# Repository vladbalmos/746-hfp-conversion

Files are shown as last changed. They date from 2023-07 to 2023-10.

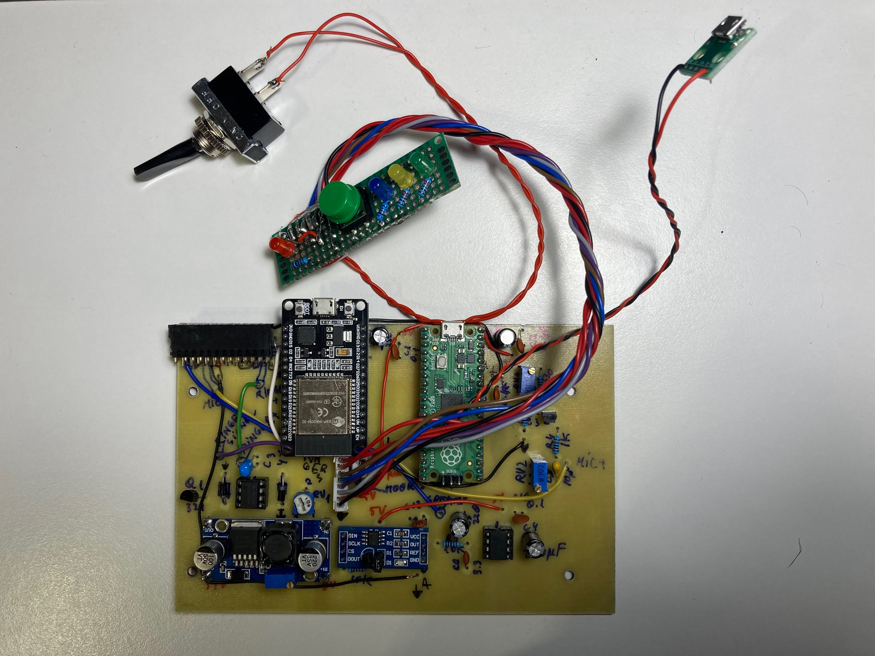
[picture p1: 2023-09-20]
img/main-board-pcb-front.jpg

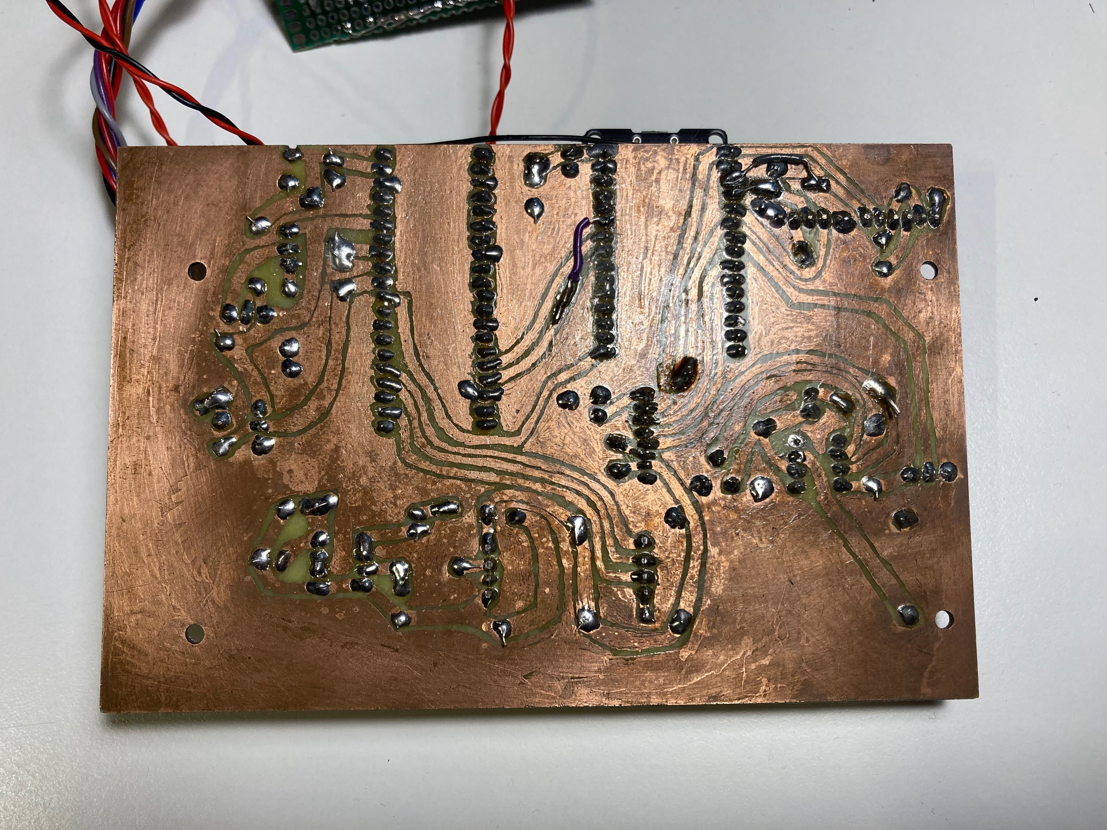
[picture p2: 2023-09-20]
img/main-board-pcb-back.jpg

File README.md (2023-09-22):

## British GPO 746 bluetooth conversion (HFP)

Firmware and hardware related resources for adding hands-free bluetooth support to a 746 british phone.

## Hardware requirements

* esp32 devboard (v1)
* Raspberry PI Pico
* external DAC (TLC5615)
* GPO 746 telephone

## Software dependencies

* esp-idf (v5.1)
* pico-sdk ( >= v1.5.0)
* opencd (optional)
* picoprobe (optiona)

## Audio input/output

In a nutshell, the ESP32 is configured with `SCO data path = HCI`, this enables the improved mSBC codec on some AGs; the audio in/out is received/sent from/to a Raspberry Pi Pico I2C slave, acting as a recording/playback device.  
The microphone is sampled using the Pico's 12bit ADC, while the earpiece speaker is driven by a buffered 10bit external DAC which interfaces with the Pico using SPI.

This is more complicated than it should mostly due to my lack of experience with the ESP32 and lack of a propper external ADC.  
My initial plan was to use the ESP32's ADC & DAC simultaneous, but the I've run into the following problems:
1. the ADC & DAC cannot be used at the same time in DMA Mode, since they both share the same DMA fifo of the I2S0 peripheral: [ADC continuous mode Hardware Limitations](https://docs.espressif.com/projects/esp-idf/en/v5.1/esp32/api-reference/peripherals/adc_continuous.html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) - I couldn't find any proper way of making it work
2. even if both ADC & DAC could work in continuous DMA mode, the ADC configuration doesn't allow sampling frequencies below 20khz (for mSBC & CVSD codecs a lower sampling rate is required: 16khz, 8khz respectively)
3. the ESP32 doesn't have an analog ground which makes both the ADC & DAC really noisy

In a previous iteration of the project, both the Pico and the external DAC were connected to the ESP32 via SPI, but it struggled to keep a constant rate of sending/receiving PCM samples during an active call because each PCM sample required its own SPI transaction (both the Pico and the TLC5615 support only 2 byte transactions) - this caused horrible audio on both ends.

## Audio transmission
The Pico is configured as a slave I2C device receiving and transmitting audio data at the master's request (ESP32). Data is transmitted via a basic protocol built on top of I2C which consists of 5 commands. Each command is encoded as a 16 bit uint. The first 8 MSB encode the command code and the last 8 LSB encode any arguments the command might have.  
Commands:  

* AUDIO_ENABLE  
    Enable ADC/DAC. The sample rate is given as a parameter
* AUDIO_DISABLE  
    Disable ADC/DAC
* AUDIO_POLL
    Poll the slave for new audio data sampled by the ADC. If slave returns `true`, the AUDIO_RECEIVE command is sent to the slave to receive the PCM samples
* AUDIO_TRANSMIT
    Sent by the master to transmit PCM samples for playback
* AUDIO_RECEIVE
    Sent by the master to receive new PCM samples from the ADC

Basic data flow between ESP32 and PICO:

    1. (master) send AUDIO_ENABLE command
       (slave) initialize ADC & DAC using the sample rate encoded in the command
       (slave) respond with OK
    2. (master) transmit any buffered PCM samples for playback (AUDIO_TRANSMIT)
       (slave) receive PCM samples and transmit to DAC via DMA
    3. (master) poll slave for new samples (AUDIO_POLL). If reply is OK, send AUDIO_RECEIVE command to receive new samples

## Functions

Almost all the existing features of the GPO 746 are preserved once paired via Bluetooth HFP:

* Ringing works when an incoming call is detected. The ringer is driven by a AC coupled PWM 20hz signal amplified to 34V using a DC-DC voltage booster module.
* Earpiece / microphone
* Dialing via the rotary dialer works as expected

Visual indicator LEDs available for:

* power
* ringing
* bluetooth connection state
* handset on/off hook

A schematic on how to physically connect the phone to the board will be added soon.

## Building

The boards need to be separately flashed using the code in `src`.

### esp32

    cd src/esp32
    source /path/to/esp-idf/export.sh
    idf.py build flash

### pico
If using picoprobe and opencd:

    # open pico-install.sh.template and change the path to opencd binary
    # rename pico-install.sh.template to pico-install.sh
    # make pico-install.sh executable
    # copy pico-install.sh to a folder which is in your $PATH (I usually place this little scripts in ~/bin)
    cd src/pico
    make install

If not using picoprobe & opencd just build and flash using the manual steps provided in the getting started pico-sdk guide

## PCBs
The device is split into two PCBs, a main board and a control board. The main board houses all the relevant components for bluetooth and audio while the control board contains the indicator LEDs and a microswitch for toggling bluetooth pairing. The schematics and PCB designs were done using KiCad, all documents are inside the `hw` folder. I designed the main board to be single sided, but the pcb design file contains traces and vias for a two sided board only to pass DRC validation and given that I manually trace and etch my PCBs I cannot guarantee that the final designs are good enough for sending to a PCB manufacturer. Inspect the designs and tweak accordingly before ordering a set of boards. You can find some pictures of the boards in the `img` folder. 

A 3d printed case model will be available in the future inside `hw/3d-prints`.

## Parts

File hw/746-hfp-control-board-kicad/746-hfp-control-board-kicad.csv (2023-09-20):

Source: | /home/vlad/Development/hw/esp32/projects/746-bt-conversion/hw/746-hfp-control-board-kicad/746-hfp-control-board-kicad.kicad_sch
Date: | Wed 20 Sep 2023 21:17:07 EEST
Tool: | Eeschema 7.0.7-7.0.7~ubuntu22.04.1
Generator: | /usr/share/kicad/plugins/bom_csv_grouped_by_value.py
Component Count: | 11
Collated Components:
Item | Qty | Reference(s) | Value | LibPart | Footprint | Datasheet | DNP
1 | 4 | D1, D2, D3, D4 | LED | Device:LED | LED_THT:LED_D5.0mm | ~
2 | 1 | J1 | Control_board_Connector | Connector:Conn_01x08_Socket | Connector_PinSocket_2.54mm:PinSocket_1x08_P2.54mm_Vertical | ~
3 | 2 | R1, R3 | 220 | Device:R | Resistor_THT:R_Axial_DIN0207_L6.3mm_D2.5mm_P10.16mm_Horizontal | ~
4 | 1 | R2 | 2k | Device:R | Resistor_THT:R_Axial_DIN0207_L6.3mm_D2.5mm_P10.16mm_Horizontal | ~
5 | 1 | R4 | 1k | Device:R | Resistor_THT:R_Axial_DIN0207_L6.3mm_D2.5mm_P10.16mm_Horizontal | ~
6 | 1 | SW1 | SW_Push | Switch:SW_Push | Button_Switch_THT:SW_PUSH_6mm_H5mm | ~
7 | 1 | SW2 | SW_SPST | Switch:SW_SPST | Connector_PinHeader_2.54mm:PinHeader_1x02_P2.54mm_Vertical | ~

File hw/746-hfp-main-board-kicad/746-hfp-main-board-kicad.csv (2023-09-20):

Source: | /home/vlad/Development/hw/esp32/projects/746-bt-conversion/hw/746-hfp-main-board-kicad/746-hfp-main-board-kicad.kicad_sch
Date: | Wed 20 Sep 2023 21:15:39 EEST
Tool: | Eeschema 7.0.7-7.0.7~ubuntu22.04.1
Generator: | /usr/share/kicad/plugins/bom_csv_grouped_by_value.py
Component Count: | 44
Collated Components:
Item | Qty | Reference(s) | Value | LibPart | Footprint | Datasheet | DNP | Sim.Device | Sim.Params | Sim.Pins | Sim.Type
1 | 3 | C1, C2, C13 | 0.1uf | Device:C | Capacitor_THT:C_Disc_D4.7mm_W2.5mm_P5.00mm | ~
2 | 1 | C3 | 47uF | Device:C | Capacitor_THT:C_Radial_D6.3mm_H11.0mm_P2.50mm | ~
3 | 4 | C4, C5, C11, C12 | 220uF | Device:C_Polarized | Capacitor_THT:C_Radial_D6.3mm_H11.0mm_P2.50mm | ~
4 | 1 | C6 | 3.3nF | Device:C | Capacitor_THT:C_Disc_D4.7mm_W2.5mm_P5.00mm | ~
5 | 1 | C8 | 10uF | Device:C | Capacitor_THT:C_Disc_D4.7mm_W2.5mm_P5.00mm | ~
6 | 1 | C9 | 0.1uF | Device:C | Capacitor_THT:C_Disc_D4.7mm_W2.5mm_P5.00mm | ~
7 | 1 | C10 | 0.1uF | Device:C | Capacitor_THT:C_Radial_D6.3mm_H11.0mm_P2.50mm | ~
8 | 2 | D1, D2 | 1N5819 | Device:D_Schottky | Diode_THT:D_DO-41_SOD81_P10.16mm_Horizontal | ~
9 | 1 | J1 | 5V | :Conn_01x01_Socket_1 | Connector_PinSocket_2.54mm:PinSocket_1x01_P2.54mm_Vertical | ~
10 | 1 | J2 | GND | :Conn_01x01_Socket_2 | Connector_PinSocket_2.54mm:PinSocket_1x01_P2.54mm_Vertical | ~
11 | 1 | J3 | 34V | :Conn_01x01_Socket_3 | Connector_PinSocket_2.54mm:PinSocket_1x01_P2.54mm_Vertical | ~
12 | 1 | J4 | GND | Connector:Conn_01x01_Socket | Connector_PinSocket_2.54mm:PinSocket_1x01_P2.54mm_Vertical | ~
13 | 4 | J5, J9, J10, J11 | Conn_01x01_Socket | Connector:Conn_01x01_Socket | Connector_PinSocket_2.54mm:PinSocket_1x01_P2.54mm_Vertical | ~
14 | 1 | J6 | Conn_01x01_Socket | :Conn_01x01_Socket_3 | Connector_PinSocket_2.54mm:PinSocket_1x01_P2.54mm_Vertical | ~
15 | 1 | J7 | Conn_01x01_Socket | :Conn_01x01_Socket_2 | Connector_PinSocket_2.54mm:PinSocket_1x01_P2.54mm_Vertical | ~
16 | 1 | J8 | Conn_01x01_Socket | :Conn_01x01_Socket_1 | Connector_PinSocket_2.54mm:PinSocket_1x01_P2.54mm_Vertical | ~
17 | 1 | J12 | Phone_Connector | Connector:Conn_01x12_Socket | Connector_PinSocket_2.54mm:PinSocket_1x12_P2.54mm_Vertical | ~
18 | 1 | J13 | ESP32_Left_Pins | Connector:Conn_01x15_Pin | Connector_PinSocket_2.54mm:PinSocket_1x15_P2.54mm_Vertical | ~
19 | 1 | J14 | ESP32_Right_Pins | :Conn_01x15_Pin_1 | Connector_PinSocket_2.54mm:PinSocket_1x15_P2.54mm_Vertical | ~
20 | 1 | J15 | Power_Connector | Connector_Generic:Conn_01x02 | Connector_JST:JST_XH_B2B-XH-A_1x02_P2.50mm_Vertical | ~
21 | 1 | J17 | Control_board_connector | Connector:Conn_01x08_Pin | Connector_JST:JST_PH_B8B-PH-K_1x08_P2.00mm_Vertical | ~
22 | 1 | J18 | Conn_01x01_Socket | :Conn_01x01_Socket_4 | Connector_PinSocket_2.54mm:PinSocket_1x01_P2.54mm_Vertical | ~
23 | 1 | Q1 | 2N7000 | Simulation_SPICE:NMOS | Package_TO_SOT_THT:TO-92 | https://ngspice.sourceforge.io/docs/ngspice-manual.pdf |  | NMOS |  | 1=D 2=G 3=S | VDMOS
24 | 2 | R3, R7 | 10k | Device:R | Resistor_THT:R_Axial_DIN0207_L6.3mm_D2.5mm_P10.16mm_Horizontal | ~
25 | 1 | R4 | 1k | Device:R | Resistor_THT:R_Axial_DIN0207_L6.3mm_D2.5mm_P10.16mm_Horizontal | ~
26 | 1 | R5 | 330 | Device:R | Resistor_THT:R_Axial_DIN0207_L6.3mm_D2.5mm_P10.16mm_Horizontal | ~
27 | 1 | R6 | 100k | Device:R | Resistor_THT:R_Axial_DIN0207_L6.3mm_D2.5mm_P10.16mm_Horizontal | ~
28 | 1 | RV1 | 100k | Device:R_Potentiometer_Trim | Potentiometer_THT:Potentiometer_Runtron_RM-065_Vertical | ~
29 | 1 | RV2 | 10k | Device:R_Potentiometer_Trim | Potentiometer_THT:Potentiometer_Bourns_3296W_Vertical | ~
30 | 1 | RV3 | 100k | Device:R_Potentiometer_Trim | Potentiometer_THT:Potentiometer_Bourns_3296W_Vertical | ~
31 | 1 | U2 | Pico | MCU_RaspberryPi_and_Boards:Pico | MCU_RaspberryPi_and_Boards:RPi_Pico_SMD_TH
32 | 1 | U3 | TL431P | Reference_Voltage:TL431P | Package_TO_SOT_THT:TO-92_Inline_Wide | http://www.ti.com/lit/ds/symlink/tl431.pdf
33 | 1 | U4 | LM358 | Amplifier_Operational:LM358 | Package_DIP:DIP-8_W7.62mm_Socket_LongPads | http://www.ti.com/lit/ds/symlink/lm2904-n.pdf
34 | 1 | U5 | UA741 | Simulation_SPICE:OPAMP | Package_DIP:DIP-8_W7.62mm_Socket_LongPads | ~ |  | SPICE | type="X" model="OPAMP" lib="" | 1=1 2=2 3=3 4=4 5=5

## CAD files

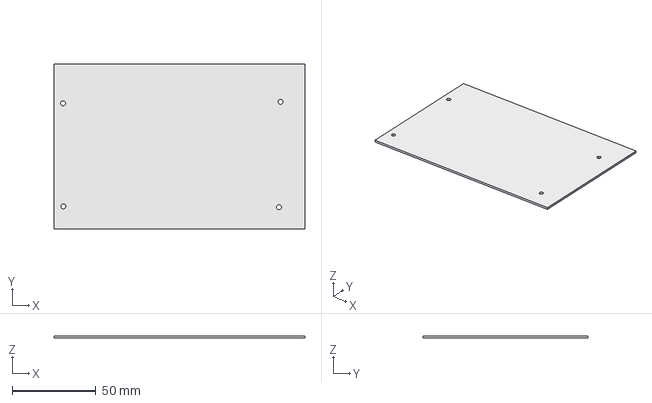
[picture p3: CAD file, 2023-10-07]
hw/3d-prints/enclosure/enclosure.FCStd
150.0 x 98.5 x 1.45 mm

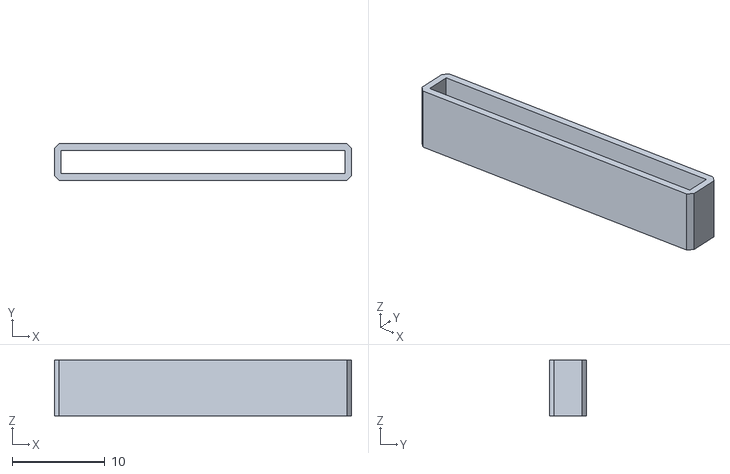
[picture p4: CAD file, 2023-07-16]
hw/3d-prints/header-pin-connector-housing/header-pin-connector-housing-Body.stl
32.0 x 4.00 x 6.00

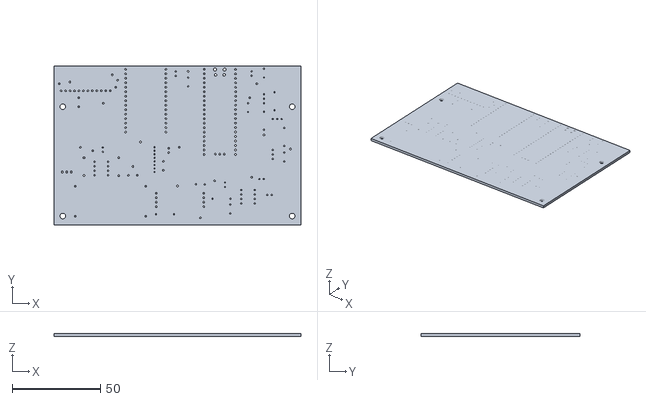
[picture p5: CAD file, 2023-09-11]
hw/3d-prints/pcb-holes-template/pcb-holes.stl
140.0 x 90.0 x 1.58

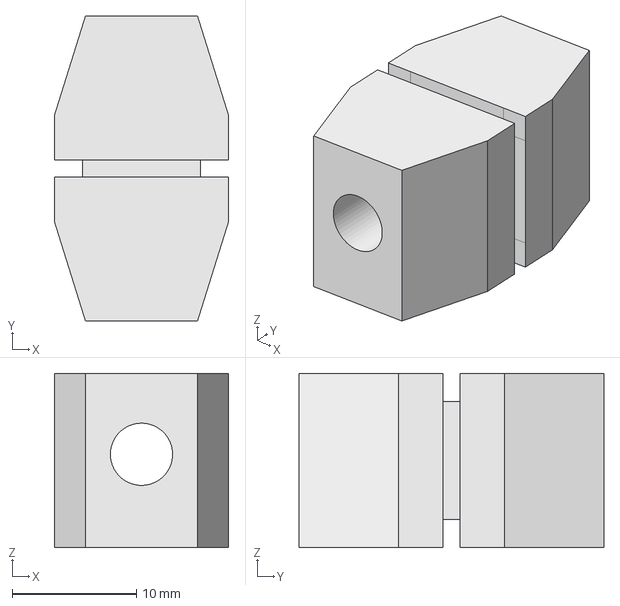
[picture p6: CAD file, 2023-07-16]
hw/3d-prints/strain-relief/connector-strain-relief.FCStd
14.0 x 24.5 x 14.0 mm

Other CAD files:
hw/3d-prints/header-pin-connector-housing/header-pin-connector-housing.FCStd
hw/3d-prints/strain-relief/connector-strain-relief-BodySketch001.stl

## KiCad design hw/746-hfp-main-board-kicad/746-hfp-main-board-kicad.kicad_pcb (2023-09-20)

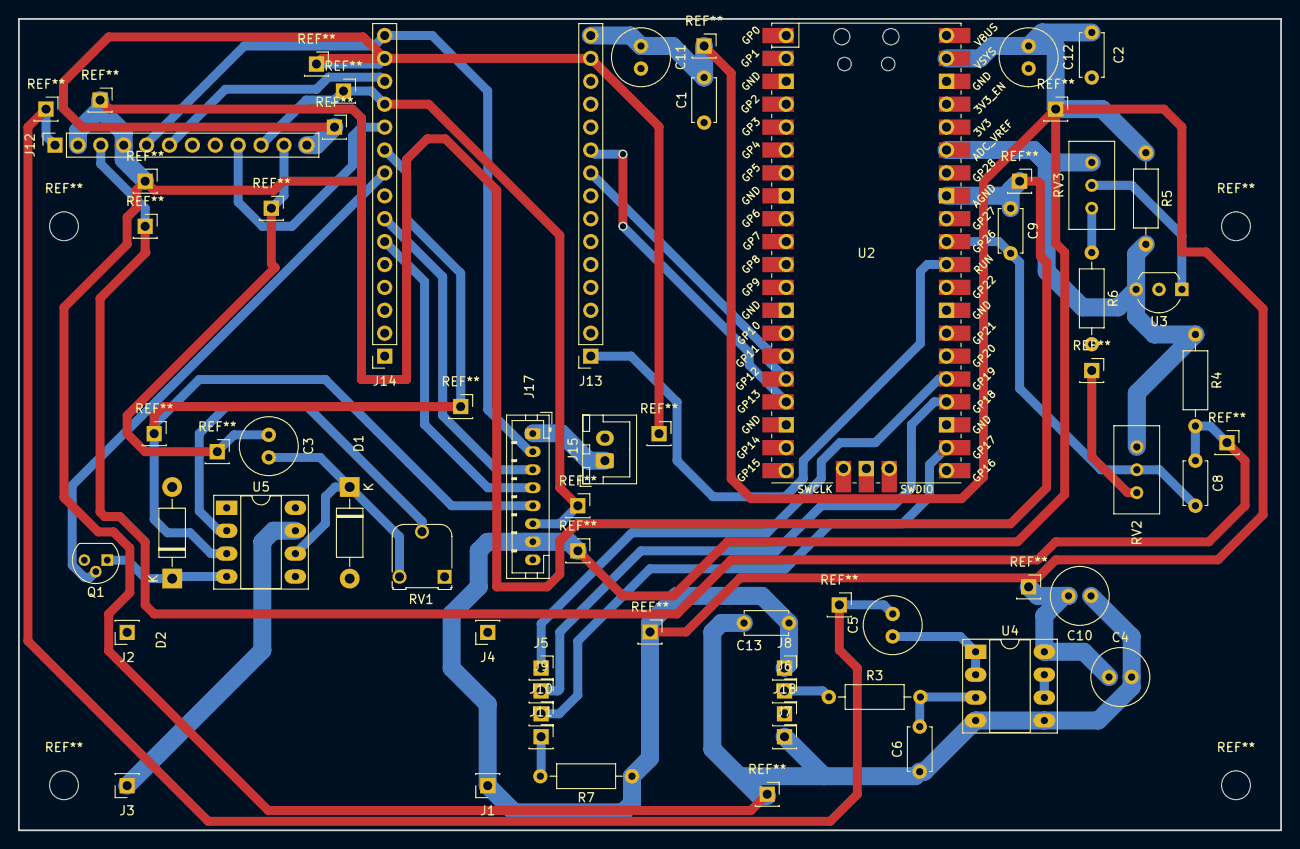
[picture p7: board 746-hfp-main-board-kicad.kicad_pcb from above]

Board: 2 copper layers, 140.0 x 90.0 mm, 44 parts (0 on the bottom side), 33 nets.

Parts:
C1, C2, C13: 0.1uf; C_Disc_D4.7mm_W2.5mm_P5.00mm
C3: 47uF; C_Radial_D6.3mm_H11.0mm_P2.50mm
C4, C5, C11, C12: 220uF; C_Radial_D6.3mm_H11.0mm_P2.50mm
C6: 3.3nF; C_Disc_D4.7mm_W2.5mm_P5.00mm
C8: 10uF; C_Disc_D4.7mm_W2.5mm_P5.00mm
C9: 0.1uF; C_Disc_D4.7mm_W2.5mm_P5.00mm
C10: 0.1uF; C_Radial_D6.3mm_H11.0mm_P2.50mm
D1, D2: 1N5819; D_DO-41_SOD81_P10.16mm_Horizontal
J1: 5V; PinSocket_1x01_P2.54mm_Vertical
J2, J4: GND; PinSocket_1x01_P2.54mm_Vertical
J3: 34V; PinSocket_1x01_P2.54mm_Vertical
J5, J6, J7, J8, J9, J10, J11, J18: Conn_01x01_Socket; PinSocket_1x01_P2.54mm_Vertical
J12: Phone_Connector; PinSocket_1x12_P2.54mm_Vertical
J13: ESP32_Left_Pins; PinSocket_1x15_P2.54mm_Vertical
J14: ESP32_Right_Pins; PinSocket_1x15_P2.54mm_Vertical
J15: Power_Connector; JST_XH_B2B-XH-A_1x02_P2.50mm_Vertical
J17: Control_board_connector; JST_PH_B8B-PH-K_1x08_P2.00mm_Vertical
Q1: IRFZ44N; TO-92
R3, R7: 10k; R_Axial_DIN0207_L6.3mm_D2.5mm_P10.16mm_Horizontal
R4: 1k; R_Axial_DIN0207_L6.3mm_D2.5mm_P10.16mm_Horizontal
R5: 330; R_Axial_DIN0207_L6.3mm_D2.5mm_P10.16mm_Horizontal
R6: 100k; R_Axial_DIN0207_L6.3mm_D2.5mm_P10.16mm_Horizontal
RV1: 100k; Potentiometer_Runtron_RM-065_Vertical
RV2: 10k; Potentiometer_Bourns_3296W_Vertical
RV3: 100k; Potentiometer_Bourns_3296W_Vertical
U2: Pico; RPi_Pico_SMD_TH
U3: TL431P; TO-92_Inline_Wide
U4: LM358; DIP-8_W7.62mm_Socket_LongPads
U5: UA741; DIP-8_W7.62mm_Socket_LongPads

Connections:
+3.3V: J12.5, J14.15, J17.2
+3.3V_Clean: R4.1, R5.2, RV2.3, RV3.1, U2.35 (ADC_VREF), U3.1 (K)
+5V: C1.2, C2.2, C4.1, C10.2, C11.1, C12.1, C13.1, J1.1, J8.1, J13.15, J17.7, R5.1, R7.1, U2.39 (VSYS), U4.8 (V+)
+5V_pre_switch: J15.1, J17.1
+34V: J3.1, U5.7 (V+)
Audio_SCL (27): J13.10, U2.17 (GPIO13)
Audio_SDA (26): J13.9, U2.16 (GPIO12)
BT_LED_STATE (19): J14.6, J17.4
DAC_CS (17): J10.1, U2.22 (GPIO17)
DAC_SCLK (18): J9.1, U2.24 (GPIO18)
DAC_TX_Din (19): J5.1, U2.25 (GPIO19)
DAC_Vout: J6.1, R3.1
DOut: J11.1, R7.2
Dialer (15): J12.6, J14.13
ENABLE_PAIRING_BTN (18): J14.7, J17.3
GND: C1.1, C2.1, C11.2, C12.2, D1.2 (A), D2.2 (A), J2.1, J4.1, J12.7, J12.8, J12.12, J13.14, J14.14, J15.2, J17.8, Q1.3 (S), R6.2, RV1.1, RV2.1, U2.3 (GND), U2.8 (GND), U2.13 (GND), U2.18 (GND), U2.23 (GND), U2.28 (GND), U2.38 (GND)
GNDA: C4.2, C6.1, C9.1, C10.1, C13.2, J7.1, J12.2, J12.4, U2.33 (AGND), U4.4 (V-), U4.5 (+)
HookSwitchOut (2): J12.10, J14.12, J17.6
HookSwitchPower (4): J12.9, J14.11
Mic+: C8.1, J12.3, R4.2
Mosfet_Drain: D2.1 (K), Q1.1 (D), U5.4 (V-)
unnamed: C3.2, D1.1 (K), RV1.3, U5.6
unnamed: R6.1, RV3.3
unnamed: C8.2, C9.2, RV2.2, U2.31 (GPIO26_ADC0)
unnamed: C6.2, R3.2, U4.3 (+)
unnamed: C5.1, U4.1, U4.2 (-)
unnamed: U4.6 (-), U4.7
unnamed: RV1.2, U5.2 (-)
Pico_Enable: J13.1, U2.30 (RUN)
Ringer+: C3.1, J12.11
RingerEnabled (17): J14.9, Q1.2 (G)
RingerSignal (16): J14.10, J17.5, U5.3 (+)
Speaker+: C5.2, J12.1

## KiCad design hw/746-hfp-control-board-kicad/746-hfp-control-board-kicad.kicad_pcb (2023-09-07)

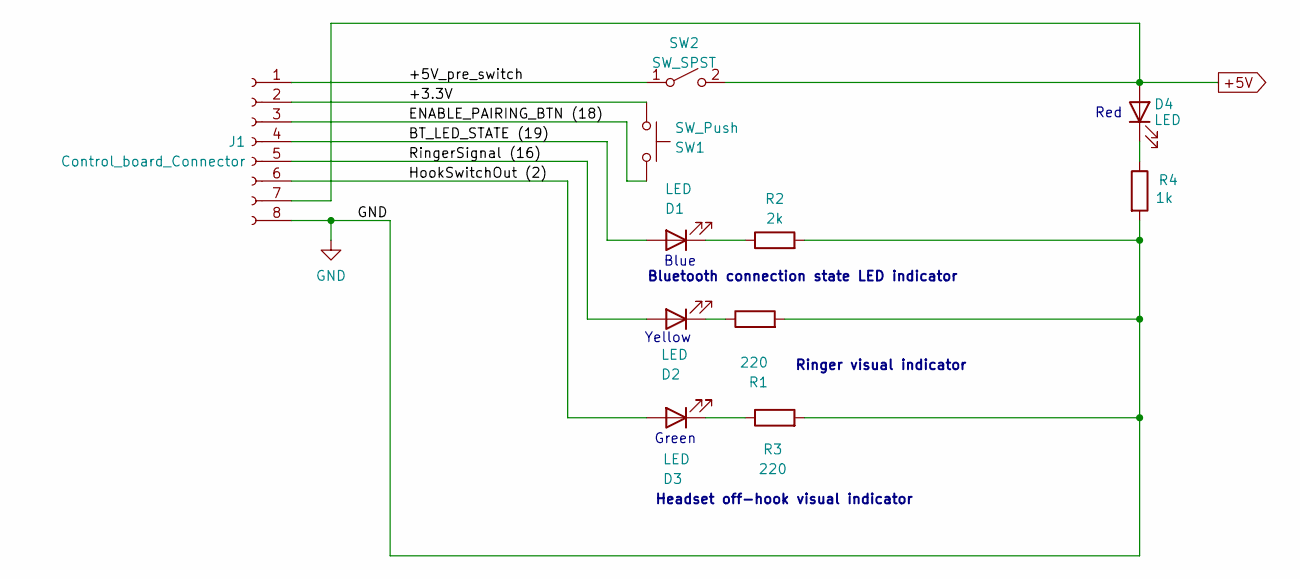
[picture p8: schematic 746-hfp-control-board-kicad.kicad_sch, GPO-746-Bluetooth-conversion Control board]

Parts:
D1, D2, D3, D4: LED; LED_D5.0mm
J1: Control_board_Connector; PinSocket_1x08_P2.54mm_Vertical
R1, R3: 220; R_Axial_DIN0207_L6.3mm_D2.5mm_P10.16mm_Horizontal
R2: 2k; R_Axial_DIN0207_L6.3mm_D2.5mm_P10.16mm_Horizontal
R4: 1k; R_Axial_DIN0207_L6.3mm_D2.5mm_P10.16mm_Horizontal
SW1: SW_Push; SW_PUSH_6mm_H5mm
SW2: SW_SPST; PinHeader_1x02_P2.54mm_Vertical

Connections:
+5V: D4.2 (A), J1.7, SW2.2 (B)
/+3.3V: J1.2, SW1.1
/+5V_pre_switch: J1.1, SW2.1 (A)
/BT_LED_STATE (19): D1.2 (A), J1.4
/ENABLE_PAIRING_BTN (18): J1.3, SW1.2
/HookSwitchOut (2): D3.2 (A), J1.6
/RingerSignal (16): D2.2 (A), J1.5
GND: J1.8, R1.2, R2.2, R3.2, R4.2
unnamed: D1.1 (K), R2.1
unnamed: D2.1 (K), R1.1
unnamed: D3.1 (K), R3.1
unnamed: D4.1 (K), R4.1

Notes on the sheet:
Headset off-hook visual indicator
Yellow
Blue
Bluetooth connection state LED indicator
Red
Green
Ringer visual indicator

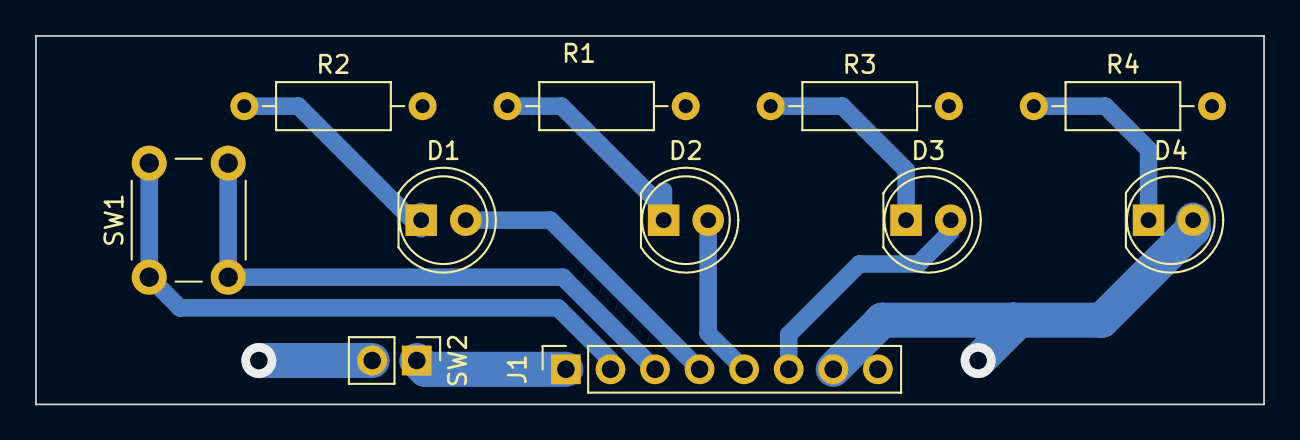
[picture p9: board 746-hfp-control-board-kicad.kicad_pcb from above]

Board: 2 copper layers, 70.0 x 21.0 mm, 11 parts (0 on the bottom side), 12 nets.

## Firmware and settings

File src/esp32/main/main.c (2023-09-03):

#include <math.h>
#include <stdio.h>
#include <string.h>
#include <inttypes.h>
#include "driver/spi_master.h"
#include "freertos/FreeRTOS.h"
#include "freertos/task.h"
#include "freertos/queue.h"
#include "driver/gpio.h"
#include "driver/dac_continuous.h"
#include "esp_bt.h"
#include "esp_bt_main.h"
#include "nvs.h"
#include "nvs_flash.h"
#include "esp_log.h"
#include "bt.h"
#include "dialer.h"
#include "ringer.h"
#include "bt_state_led.h"

#define TAG "MAIN"

#define ESP_INTR_FLAG_DEFAULT 0

#define DIALER_PULSE_PIN 15
#define HOOK_POWER_PIN 4
#define HOOK_SWITCH_PIN 2
#define RINGER_SIGNAL_PIN 16
#define RINGER_ENABLE_PIN 17
#define ENABLE_PAIRING_PIN 18
#define BT_STATE_LED_PIN 19

static uint8_t incoming_call_alert = 0;
static uint8_t call_in_progress = 0;
static uint32_t last_irq_time_ms = 0;


static void IRAM_ATTR gpio_isr_enable_pairing_handler(void* arg) {
    QueueHandle_t q = (QueueHandle_t) arg;
    uint32_t now = xTaskGetTickCountFromISR() * portTICK_PERIOD_MS;
    uint32_t diff_ms = now - last_irq_time_ms;
    last_irq_time_ms = now;
    
    if (diff_ms < 100) {
        return;
    }

    bt_msg_t msg = bt_create_msg(BT_EV_PAIR_BTN_ACTIVITY, NULL, 0);
    xQueueSendFromISR(q, &msg, NULL);
}

void on_headset_state_change(uint8_t state) {
    if (state && incoming_call_alert) {
        bt_task_send(BT_EV_ANSWER_CALL, NULL, 0);
        ringer_enable(0);
        return;
    }
    
    if (!state && call_in_progress) {
        bt_task_send(BT_EV_CALL_HANGUP, NULL, 0);
        return;
    }
}

void on_end_dialing(const char *number, uint8_t number_length) {
    if (!number_length) {
        return;
    }
    
    if (dialer_get_headset_state()) {
        bt_task_send(BT_EV_DIAL_NUMBER, (void *) number, (size_t) number_length);
        ESP_LOGI(TAG, "Dialing number: %s. Number length: %d", number, number_length);
    }
}

static void main_task_handler(void *arg) {
    QueueHandle_t bt_msg_queue = xQueueCreate(10, sizeof(bt_msg_t));
    assert(bt_msg_queue != NULL);

    ESP_ERROR_CHECK(gpio_install_isr_service(ESP_INTR_FLAG_DEFAULT));
    
    gpio_config_t input_conf = {};
    input_conf.intr_type = GPIO_INTR_ANYEDGE;
    input_conf.mode = GPIO_MODE_INPUT;
    input_conf.pin_bit_mask = 1ULL << ENABLE_PAIRING_PIN;
    input_conf.pull_up_en = 0;
    input_conf.pull_down_en = 1;
    ESP_ERROR_CHECK(gpio_config(&input_conf));
    ESP_ERROR_CHECK(gpio_isr_handler_add(ENABLE_PAIRING_PIN, gpio_isr_enable_pairing_handler, (void *) bt_msg_queue));
    
    // Init bluetooth connection state led
    bt_state_led_init(BT_STATE_LED_PIN);

    // Initialize phone interface
    dialer_init(DIALER_PULSE_PIN, HOOK_POWER_PIN, HOOK_SWITCH_PIN, on_headset_state_change, NULL, NULL, on_end_dialing);
    dialer_enable(1);
    
    ringer_init(RINGER_ENABLE_PIN, RINGER_SIGNAL_PIN);
    
    // Bluetooth initialization
    esp_err_t ret = nvs_flash_init();
    if (ret == ESP_ERR_NVS_NO_FREE_PAGES) {
        ESP_ERROR_CHECK(nvs_flash_erase());
        ret = nvs_flash_init();
    }
    ESP_ERROR_CHECK(ret);

    ESP_ERROR_CHECK(esp_bt_controller_mem_release(ESP_BT_MODE_BLE));
    
    esp_err_t err;
    esp_bt_controller_config_t bt_cfg = BT_CONTROLLER_INIT_CONFIG_DEFAULT();
    if ((err = esp_bt_controller_init(&bt_cfg)) != ESP_OK) {
        ESP_LOGE(TAG, "%s initialize controller failed: %s\n", __func__, esp_err_to_name(ret));
        return;
    }

    if ((err = esp_bt_controller_enable(ESP_BT_MODE_CLASSIC_BT)) != ESP_OK) {
        ESP_LOGE(TAG, "%s enable controller failed: %s\n", __func__, esp_err_to_name(ret));
        return;
    }

    if ((err = esp_bluedroid_init()) != ESP_OK) {
        ESP_LOGE(TAG, "%s initialize bluedroid failed: %s\n", __func__, esp_err_to_name(ret));
        return;
    }

    if ((err = esp_bluedroid_enable()) != ESP_OK) {
        ESP_LOGE(TAG, "%s enable bluedroid failed: %s\n", __func__, esp_err_to_name(ret));
        return;
    }
    
    bt_init(bt_msg_queue);
    
    bt_msg_t msg;
    
    ESP_LOGI(TAG, "10 ms = %"PRId32" tick", pdMS_TO_TICKS(10));

    while(1) {
        if (xQueueReceive(bt_msg_queue, &msg, portMAX_DELAY) != pdTRUE) {
            continue;
        }

        switch (msg.ev) {
            case BT_EV_INCOMING_CALL: {
                if (!dialer_get_headset_state()) {
                    incoming_call_alert = 1;
                    if (!ringer_get_state()) {
                        ringer_enable(1);
                    }
                } else {
                    bt_task_send(BT_EV_CALL_HANGUP, NULL, 0);
                }
                ESP_LOGI(TAG, "Incoming call");
                break;
            }

            case BT_EV_OUTGOING_CALL: {
                call_in_progress = 1;
                ESP_LOGI(TAG, "Outgoing call");
                break;
            }

            case BT_EV_CALL_STATUS_IDLE: {
                if (ringer_get_state()) {
                    ringer_enable(0);
                }
                incoming_call_alert = 0;
                break;
            }

            case BT_EV_CALL_IN_PROGRESS: {
                incoming_call_alert = 0;
                call_in_progress = 1;
                ESP_LOGI(TAG, "Call in progress");
                break;
            }

            case BT_EV_CALL_HANGUP: {
                call_in_progress = 0;
                ESP_LOGI(TAG, "Call hangup");
                break;
            }
                                    
            case BT_EV_PAIR_BTN_ACTIVITY: {
                uint8_t btn_pressed = gpio_get_level(ENABLE_PAIRING_PIN);
                if (btn_pressed) {
                    bt_task_send(BT_EV_ENABLE_PAIRING, NULL, 0);
                }
                break;
            }
                                          
            case BT_EV_START_PAIRING: {
                bt_state_led_blink();
                ESP_LOGW(TAG, "Start pairing");
                break;
            }

            case BT_EV_CONNECTED: {
                bt_state_led_on();
                ESP_LOGW(TAG, "Connected");
                break;
            }

            case BT_EV_PAIRING_TIMEOUT: {
                bt_state_led_off();
                bt_task_send(BT_EV_STOP_PAIRING, NULL, 0);
                ESP_LOGW(TAG, "Pairing timeout");
                break;
            }
            case BT_EV_DISCONNECTED: {
                bt_state_led_off();
                ESP_LOGW(TAG, "Disconnected");
                break;
            }

            default: {
                ESP_LOGW(TAG, "Unhandled message %d", msg.ev);
                break;
            }
        }
    }

}

void app_main(void) {
    BaseType_t r = xTaskCreatePinnedToCore(main_task_handler, "main", 4096, NULL, 5, NULL, 1);
    assert(r == pdTRUE);
    
    while (1) {
        vTaskDelay(1000);
    }
}

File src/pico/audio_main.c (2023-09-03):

#include <stdio.h>
#include "pico/stdlib.h"
#include "hardware/adc.h"
#include "hardware/dma.h"
#include "hardware/sync.h"
#include "audio.h"
#include "debug.h"

#ifdef DEBUG_MODE
#define LED_PIN PICO_DEFAULT_LED_PIN
#define LED_TOGGLE_TIMEOUT_MS 250

static bool led_state = true;
static alarm_id_t led_toggle_alarm = 0;

static int64_t toggle_led_alarm_callback(alarm_id_t id, void *user_data) {
    led_state = !led_state;
    gpio_put(LED_PIN, led_state);
    led_toggle_alarm = add_alarm_in_ms(LED_TOGGLE_TIMEOUT_MS, toggle_led_alarm_callback, NULL, true);
    return 0;
}
#endif

// Implements an audio I2C slave device at address 32
// --------------------------------------------------
// Starts ADC sampling once a sample rate has been received from master
// and notifies master when samples are available for transmission
// 
// During each transmission cycle, fetch any available PCM samples from master and
// forward them to external DAC through SPI
int main() {
    stdio_init_all();
    
#ifdef DEBUG_MODE
    gpio_init(LED_PIN);
    gpio_set_dir(LED_PIN, GPIO_OUT);
    gpio_put(LED_PIN, led_state);
    
    led_toggle_alarm = add_alarm_in_ms(LED_TOGGLE_TIMEOUT_MS, toggle_led_alarm_callback, NULL, true);
#endif
    
    // Initialize I2C & SPI
    audio_transport_init();

    while (1) {
        audio_process_master_cmd();
    }
}

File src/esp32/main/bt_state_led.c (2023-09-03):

#include <inttypes.h>
#include "freertos/FreeRTOS.h"
#include "driver/gpio.h"
#include "esp_timer.h"

#define BT_LED_BLINK_INTERVAL_US 125 * 1000

static gpio_num_t led_pin;
static uint8_t last_led_state = 0;
static esp_timer_handle_t blink_timer;

static void blink_timer_callback(void *arg) {
    last_led_state = !last_led_state;
    gpio_set_level(led_pin, last_led_state);
}

void bt_state_led_on() {
    gpio_set_level(led_pin, 1);
    esp_timer_stop(blink_timer);
}

void bt_state_led_off() {
    gpio_set_level(led_pin, 0);
    esp_timer_stop(blink_timer);
}

void bt_state_led_blink() {
    esp_timer_create_args_t timer_args = {
        .callback = &blink_timer_callback,
        .name = "bt-led-blink-timer"
    };

    ESP_ERROR_CHECK(esp_timer_create(&timer_args, &blink_timer));
    ESP_ERROR_CHECK(esp_timer_start_periodic(blink_timer, BT_LED_BLINK_INTERVAL_US));
}

void bt_state_led_init(gpio_num_t pin) {
    led_pin = pin;

    gpio_config_t output_conf = {};
    output_conf.intr_type = GPIO_INTR_DISABLE;
    output_conf.mode = GPIO_MODE_OUTPUT;
    output_conf.pin_bit_mask = 1ULL << led_pin;
    output_conf.pull_up_en = 0;
    output_conf.pull_down_en = 0;
    ESP_ERROR_CHECK(gpio_config(&output_conf));
    bt_state_led_off();
}

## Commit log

2023-06-11 Proof of concept: Capturing ADC through DMA and writing to SPI DAC
2023-06-24 Fix DMA timing issue
2023-06-28 Fixed issue with DAC
    [audio.c]
2023-07-16 Start working on dialer
    [connector-strain-relief-BodySketch001.stl, connector-strain-relief.FCStd, header-pin-connector-housing-Body.stl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]
2023-07-25 Start clean with esp32
    [connector-strain-relief-BodySketch001.stl, connector-strain-relief.FCStd, header-pin-connector-housing-Body.stl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]
2023-07-27 Fix hook switch debouncing
    [dialer.c, main.c]
2023-07-28 Replaced printf with ESP_LOG statements
    [main.c, ringer.c]
2023-08-17 Add schematic
    [746-hfp-kicad.kicad_pcb, 746-hfp-kicad.kicad_sch]
2023-08-19 Working SPI DAC
2023-08-19 Bug fixes
    [746-hfp-kicad.kicad_sch]
2023-08-20 Start integrating Pico's ADC
    [connector-strain-relief-BodySketch001.stl, connector-strain-relief.FCStd, header-pin-connector-housing-Body.stl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]
2023-08-21 Proof of concept ADC via SPI
2023-08-22 Set correct adc dma timer
    [adc.c]
2023-08-26 Switch to i2c adc
2023-09-02 Update schematic
    [746-hfp-kicad.kicad_sch]
2023-09-03 Bug fixes. Add volume change support
    [audio.c, main.c]
2023-09-03 Add bluetooth state led and pairing controls
2023-09-04 Improve schematic
    [746-hfp-kicad.kicad_sch]
2023-09-05 Improved schematic
    [746-hfp-kicad.kicad_sch]
2023-09-05 Generate bill of materials
    [746-hfp-kicad.csv, 746-hfp-kicad.kicad_sch]
2023-09-07 Change scl pin
2023-09-07 Create pcb board
    [746-hfp-kicad.kicad_pcb, 746-hfp-kicad.kicad_sch, GPO-746-bt-control-board.kicad_sch]
2023-09-07 Rename kicad main board
    [746-hfp-main-board-kicad.csv, 746-hfp-main-board-kicad.kicad_pcb, 746-hfp-main-board-kicad.kicad_sch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]
2023-09-07 Add schematic & pcb for control board
    [746-hfp-control-board-kicad.kicad_pcb, 746-hfp-control-board-kicad.kicad_sch, 746-hfp-main-board-kicad.kicad_pcb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]
2023-09-08 Create kicad pcb
    [746-hfp-main-board-kicad.kicad_pcb, 746-hfp-main-board-kicad.kicad_sch, pcb-routing-template.FCStd]
2023-09-11 Improve kicad related
    [746-hfp-main-board-kicad.kicad_pcb, pcb-holes.stl, pcb-routing-template.FCStd]
2023-09-18 Fixed pcb
    [746-hfp-main-board-kicad.kicad_pcb, 746-hfp-main-board-kicad.kicad_sch]
2023-09-20 Fixed board
    [746-hfp-main-board-kicad.kicad_pcb, 746-hfp-main-board-kicad.kicad_sch]
2023-09-20 Added BOM
    [746-hfp-control-board-kicad.csv, 746-hfp-main-board-kicad.csv, 746-hfp-main-board-kicad.kicad_sch]
2023-10-07 Start work on enclosure
    [enclosure.FCStd]
2023-10-07 Update sketch
    [enclosure.FCStd]
